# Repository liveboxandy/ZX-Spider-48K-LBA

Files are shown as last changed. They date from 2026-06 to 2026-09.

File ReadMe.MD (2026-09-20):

# ZX 48 Spider rework by liveboxandy
## ZX Spectrum 48 clone built on the basis of the ZX Max 48 design.

The board is designed to fit into the standard ZX Spectrum 48k or ZX Spectrum + housing.

## Characteristic:

* ULA based on the CPLD system from the Altera Max7000 family (EPM7128SLC84),
* 48KB RAM,
* AY-3-8910 or AY-3-8912 sound system with stereo output,
* Kempston standard joystick interface,
* RGB video output,
* possibility of using a power supply with any polarity,
* ROM bank switch,
* board fully adapted for through hole mounting

V1.0
* Uses MiniDIN 9 Pin for RGB same as ZX Max 128 & ZX MAx PLusD rather than MinDIN 8.
* Uses same Resistor values for RED/GREEN/BLUE/BRIGHT as ZX Max 128/PlusD/3/2A. 

V1.1
* Joystick can be disabled by removing J18.
* Option to supply +/-12V to edge connector for IF1 Serial support using PS1.

V1.2
* Routed AY3-8910 IOB Bits0-7 to header J18 Pins 1(Bit0)- 8(Bit7).
* Routed AY3-891X IOA Bits0-7 to header J20 Pins 1(Bit0)- 8(Bit7).
* Changed ROM select header to 2 pin rather than 3 pin so added pullup resistor.

V1.3
* Move MiniDIN 9 Pin right by ~2mm so it aligns better with the Video hole in the 14/48K and 48K+
* cases. 

V1.4 
* Correct value of R58 to 470R
* Add jumper J9 to select either 27C256 or 28C256
* Buffer 14Mhz clock more. Use all spare gates
* Label all jumpers

V1.5
* Move position and rotation Q2
* Slight repositioning of J6 (9Pin MiniDIN), R15/16/17/18/73 and J18

V1.6
* Move J6 MiniDIN 9 right by 0.5mm and down by 1mm to better align with 48K+ case.
* Move J11 Ear/Mic right by 0.5mm to better align with 48K+ case.
* Move components below J6 and J5 down to give more space.
* Move Edge Connector left by 0.8mm to centre within 48K+ case cutout.
* Add liveboxandy's Spider 48K V1.6 to silkscreen to try to track different revisions of PCB.

V1.7
* Add R20 for auto RGB selection. can be replaced with wire link if there is a 180R-270R resistor in the cable between miniDIN Pin 2 and Scart Pin 16 or can be left unpopulated if manual selection is used.
* Add R21 and D2 for auto AV 4:3 format. Requires PS1 (+12/-12V Converter) to be fitted. If manual selection, R21 and D2 can be left unpopulated.
* If PS1 is fitted the serial comms on IF1 will still NOT work unless C1 in the IF1 is replaced with a wire link. (The IF1 expects  12VAC which it uses to create -12VDC. The DCDC converter PS1 provides -12VDC but it is blocked by C1 in the IF1.)

See https://github.com/konkotgit/ZX-48-Spider Rev 1.1 for original information on the ZX Spider, especially if you have issues.
1) with BRIGHT being low or not visible - Might not, see above.
2) Tape loading issues.

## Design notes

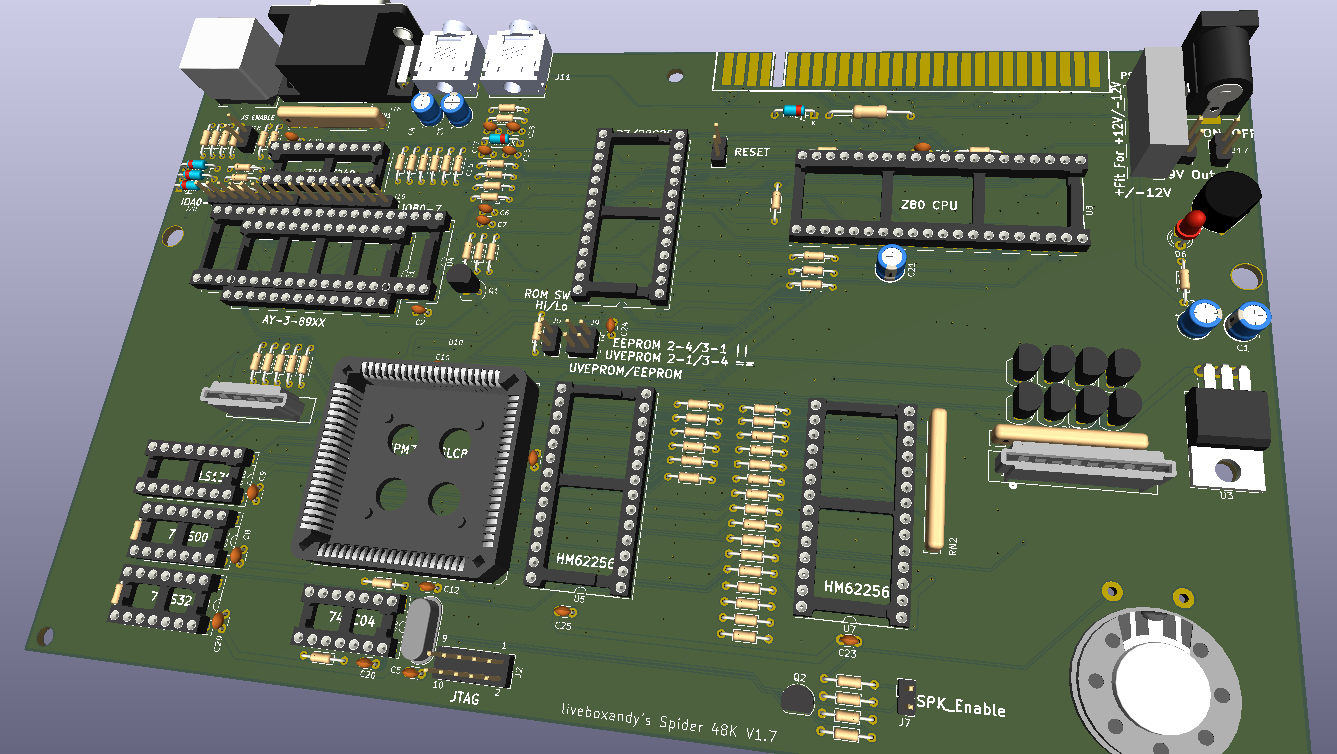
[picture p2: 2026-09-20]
ZXSpider48.png

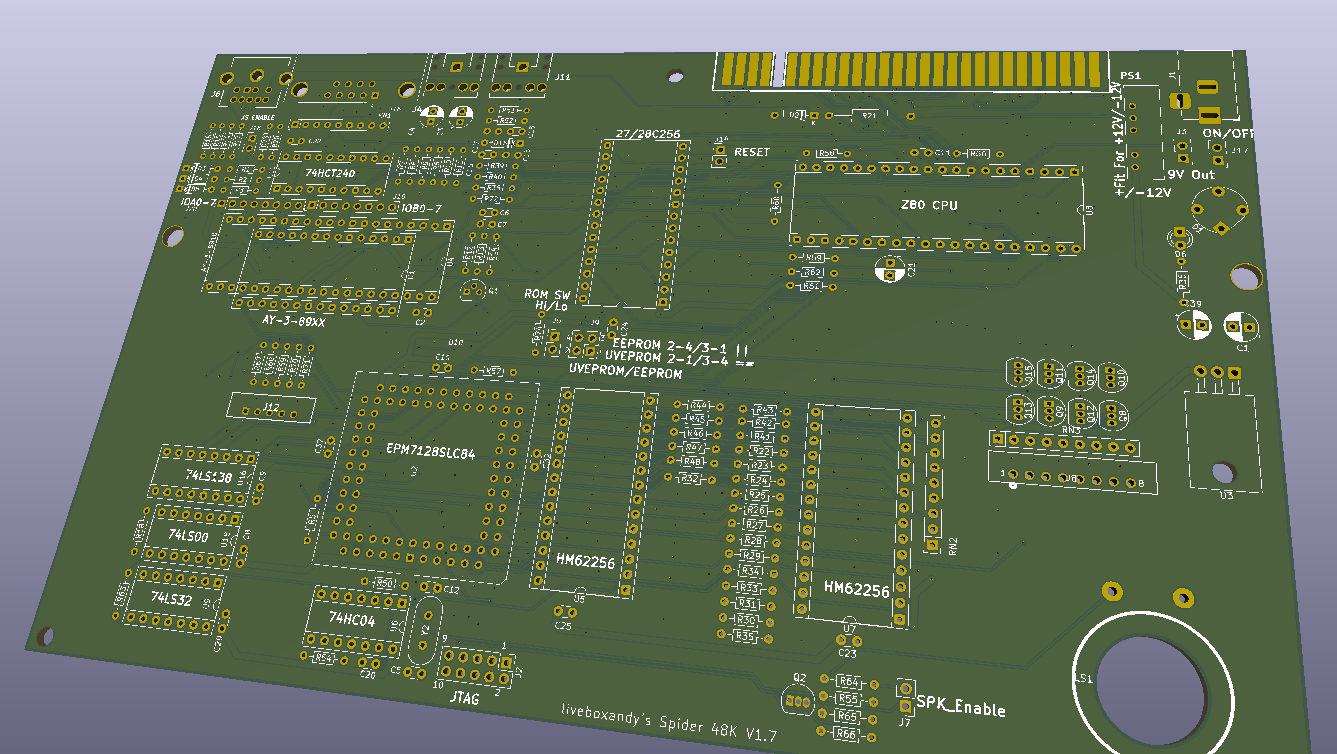
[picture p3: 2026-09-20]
ZXSpider48-Unpopulated.png

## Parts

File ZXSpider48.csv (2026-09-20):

Reference | Qty | Value | DNP | Exclude from BOM | Exclude from Board | Footprint | Datasheet
C1,C39 | 2 | 47uF |  |  |  | Capacitor_THT:CP_Radial_D5.0mm_P2.50mm
C2,C5,C6,C7,C8,C9,C10,C11,C12,C22,C23,C24,C25,C29,C32,C37 | 16 | 100n |  |  |  | Capacitor_THT:C_Disc_D3.0mm_W1.6mm_P2.50mm
C3,C4,C21 | 3 | 10uF |  |  |  | Capacitor_THT:CP_Radial_D5.0mm_P2.50mm
C15 | 1 | 10nF |  |  |  | Capacitor_THT:C_Disc_D3.0mm_W1.6mm_P2.50mm
C16 | 1 | 3.3nF |  |  |  | Capacitor_THT:C_Disc_D3.0mm_W1.6mm_P2.50mm
C17,C18 | 2 | 100nF |  |  |  | Capacitor_THT:C_Disc_D3.0mm_W1.6mm_P2.50mm
C20 | 1 | 100pF |  |  |  | Capacitor_THT:C_Disc_D3.0mm_W1.6mm_P2.50mm
D1 | 1 | Diode_Bridge |  |  |  | Diode_THT:Diode_Bridge_Round_D8.9mm
D2 | 1 | 12V |  |  |  | Diode_THT:D_DO-35_SOD27_P7.62mm_Horizontal
D3,D4,D5,D15 | 4 | 1N4148 |  |  |  | Diode_THT:D_DO-35_SOD27_P7.62mm_Horizontal
D6 | 1 | PWR LED |  |  |  | LED_THT:LED_D3.0mm
J1 | 1 | Barrel_Jack_Switch |  |  |  | Connector_BarrelJack:BarrelJack_Horizontal
J2 | 1 | JTAG |  |  |  | Connector_PinHeader_2.54mm:PinHeader_2x05_P2.54mm_Vertical
J3 | 1 | 9V |  |  |  | Connector_PinHeader_2.54mm:PinHeader_1x02_P2.54mm_Vertical
J4 | 1 | AUDIO |  |  |  | _MOD:SJ13525NGPI
J5 | 1 | ROM_SW |  |  |  | Connector_PinHeader_2.54mm:PinHeader_1x02_P2.54mm_Vertical
J6 | 1 | M-DIN KMDGX-9S-BS-1 |  |  |  | _MOD:KMDGX9SBS1 | http://service.powerdynamics.com/ec/Catalog17/Section%2011.pdf
J7 | 1 | SPK_ON_OFF |  |  |  | Connector_PinHeader_2.54mm:PinHeader_1x02_P2.54mm_Vertical
J8 | 1 | KB_CON_08 |  |  |  | _MOD:CONN_5-520315-8_TYC | 5-520315-8
J9 | 1 | UV/EEPROM |  |  |  | Connector_PinHeader_2.54mm:PinHeader_2x02_P2.54mm_Vertical
J11 | 1 | EAR/MIC |  |  |  | _MOD:SJ13525NGPI
J12 | 1 | KB_CONN_05 |  |  |  | _MOD:CONN_5-520315-5_TYC | https://www.te.com/commerce/DocumentDelivery/DDEController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
J14 | 1 | RESET |  |  |  | Connector_PinHeader_2.54mm:PinHeader_1x02_P2.54mm_Vertical
J15 | 1 | ZX_48K_EDGE |  |  |  | _MOD:ZX_BUS_A_TOP
J16 | 1 | DB9_Pins |  |  |  | Connector_Dsub:DSUB-9_Pins_Horizontal_P2.77x2.84mm_EdgePinOffset9.90mm_Housed_MountingHolesOffset11.32mm
J17 | 1 | ON/OFF |  |  |  | Connector_PinHeader_2.54mm:PinHeader_1x02_P2.54mm_Vertical
J18 | 1 | JS_ENABLE |  |  |  | Connector_PinHeader_2.54mm:PinHeader_1x02_P2.54mm_Vertical
J19 | 1 | AY3_IOB |  |  |  | Connector_PinHeader_2.54mm:PinHeader_1x08_P2.54mm_Vertical
J20 | 1 | AY3_IOA |  |  |  | Connector_PinHeader_2.54mm:PinHeader_1x08_P2.54mm_Vertical
LS1 | 1 | Speaker |  |  |  | _MOD:Speaker
PS1 | 1 | TBA_1-0522E |  |  |  | _MOD:TBA10522E | https://tracopower.com/tba1e-datasheet/
Q1 | 1 | BC517 |  |  |  | Package_TO_SOT_THT:TO-92 | https://www.onsemi.com/pub/Collateral/BC517-D74Z-D.PDF
Q2 | 1 | BC548 |  |  |  | Package_TO_SOT_THT:TO-92_Inline | https://www.onsemi.com/pub/Collateral/BC550-D.pdf
Q8,Q9,Q10,Q11,Q12,Q13,Q14,Q15 | 8 | BC560 |  |  |  | Package_TO_SOT_THT:TO-92_Inline | https://www.onsemi.com/pub/Collateral/BC556BTA-D.pdf
R1,R2,R3,R19 | 4 | 68R |  |  |  | Resistor_THT:R_Axial_DIN0204_L3.6mm_D1.6mm_P7.62mm_Horizontal
R5,R22,R23,R24,R25,R26,R27,R28,R29,R30,R31,R32,R33,R34,R35,R41,R42,R43,R44,R45,R46,R47,R48,R50,R51,R54,R57,R58 | 28 | 470R |  |  |  | Resistor_THT:R_Axial_DIN0204_L3.6mm_D1.6mm_P7.62mm_Horizontal
R6,R7 | 2 | 2K2 |  |  |  | Resistor_THT:R_Axial_DIN0204_L3.6mm_D1.6mm_P7.62mm_Horizontal
R8,R9,R10,R11 | 4 | 1K0 |  |  |  | Resistor_THT:R_Axial_DIN0204_L3.6mm_D1.6mm_P7.62mm_Horizontal
R12 | 1 | 4K7 |  |  |  | Resistor_THT:R_Axial_DIN0204_L3.6mm_D1.6mm_P7.62mm_Horizontal
R13,R14 | 2 | 150K |  |  |  | Resistor_THT:R_Axial_DIN0204_L3.6mm_D1.6mm_P7.62mm_Horizontal
R15,R16,R17,R36 | 4 | 150R |  |  |  | Resistor_THT:R_Axial_DIN0204_L3.6mm_D1.6mm_P7.62mm_Horizontal
R18,R38,R39,R40,R52,R55,R59,R60,R61,R62,R63,R67,R68,R69,R70,R71,R73,R74 | 18 | 10K |  |  |  | Resistor_THT:R_Axial_DIN0204_L3.6mm_D1.6mm_P7.62mm_Horizontal
R20 | 1 | 270R |  |  |  | Resistor_THT:R_Axial_DIN0204_L3.6mm_D1.6mm_P7.62mm_Horizontal
R21 | 1 | 150R |  |  |  | Resistor_THT:R_Axial_DIN0207_L6.3mm_D2.5mm_P15.24mm_Horizontal
R56 | 1 | 4.7K |  |  |  | Resistor_THT:R_Axial_DIN0204_L3.6mm_D1.6mm_P7.62mm_Horizontal
R64 | 1 | 0R |  |  |  | Resistor_THT:R_Axial_DIN0204_L3.6mm_D1.6mm_P7.62mm_Horizontal
R65,R66 | 2 | 33K |  |  |  | Resistor_THT:R_Axial_DIN0204_L3.6mm_D1.6mm_P7.62mm_Horizontal
R72 | 1 | 470K |  |  |  | Resistor_THT:R_Axial_DIN0204_L3.6mm_D1.6mm_P7.62mm_Horizontal
RN1,RN2,RN3 | 3 | 10K |  |  |  | Resistor_THT:R_Array_SIP9 | http://www.vishay.com/docs/31509/csc.pdf
U1 | 1 | AY-3-8912 |  |  |  | Package_DIP:DIP-28_W15.24mm_Socket | http://datasheets.diptrace.com\st_micro\M27C256B.pdf
U2 | 1 | EPM7128SLC84-10 |  |  |  | Package_LCC:PLCC-84_THT-Socket
U3 | 1 | LM7805_TO220 |  |  |  | Package_TO_SOT_THT:TO-220-3_Horizontal_TabDown | http://www.ti.com/lit/gpn/lm7800
U4 | 1 | AY-3-8910 |  |  |  | Package_DIP:DIP-40_W15.24mm_Socket
U5,U7 | 2 | HM62256 |  |  |  | Package_DIP:DIP-28_W15.24mm_Socket
U6 | 1 | 74HC04 |  |  |  | Package_DIP:DIP-14_W7.62mm_Socket | https://assets.nexperia.com/documents/data-sheet/74HC_HCT04.pdf
U8 | 1 | Z80 |  |  |  | Package_DIP:DIP-40_W15.24mm_Socket
U9 | 1 | 74LS32 |  |  |  | Package_DIP:DIP-14_W7.62mm_Socket | http://www.ti.com/lit/gpn/sn74LS32
U10 | 1 | 27/28C256 |  |  |  | Package_DIP:DIP-28_W15.24mm_Socket
U11 | 1 | 74HCT240 |  |  |  | Package_DIP:DIP-20_W7.62mm_Socket | https://assets.nexperia.com/documents/data-sheet/74HC_HCT240.pdf
U16 | 1 | 74LS138 |  |  |  | Package_DIP:DIP-16_W7.62mm_Socket | http://www.ti.com/lit/gpn/sn74LS138
U18 | 1 | 74LS00 |  |  |  | Package_DIP:DIP-14_W7.62mm_Socket | http://www.ti.com/lit/gpn/sn74ls00
Y2 | 1 | 14.000 Mhz |  |  |  | Crystal:Crystal_HC49-4H_Vertical

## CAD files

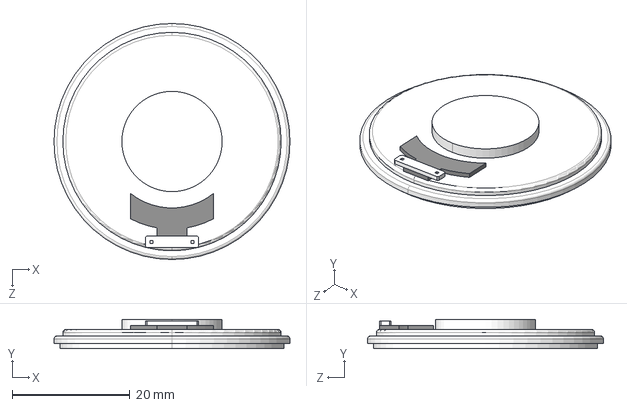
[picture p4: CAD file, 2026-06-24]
STP/GC0402MA.stp
40.0 x 4.93 x 40.0 mm

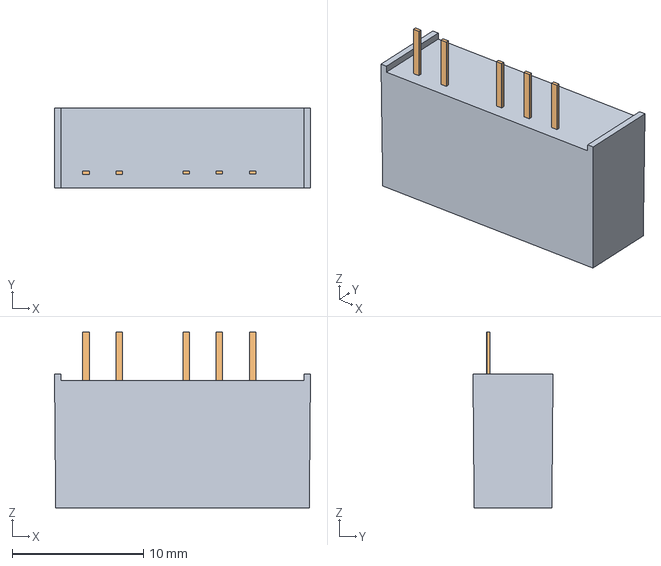
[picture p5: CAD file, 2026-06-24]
STP/TBA-1-0522E.stp
19.5 x 6.10 x 13.4 mm

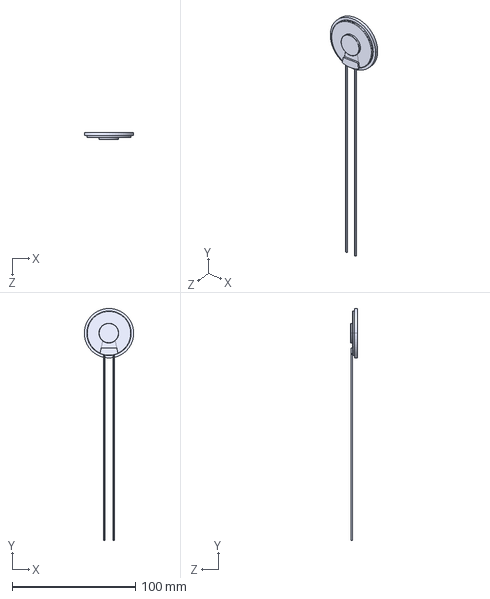
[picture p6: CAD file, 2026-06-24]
STP/CMS-40558N-L152B.stp
40.0 x 187.9 x 5.50 mm

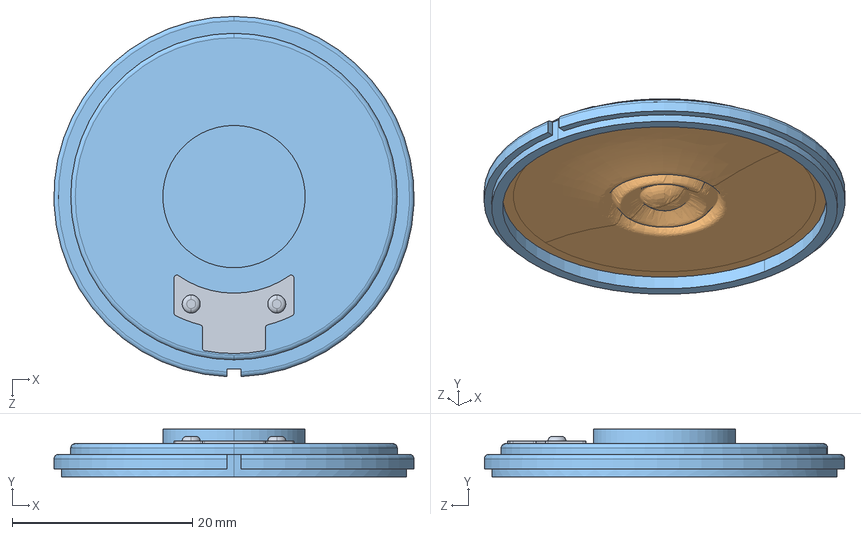
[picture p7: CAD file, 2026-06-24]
STP/CLS0402MA-1.stp
40.0 x 5.30 x 40.0 mm

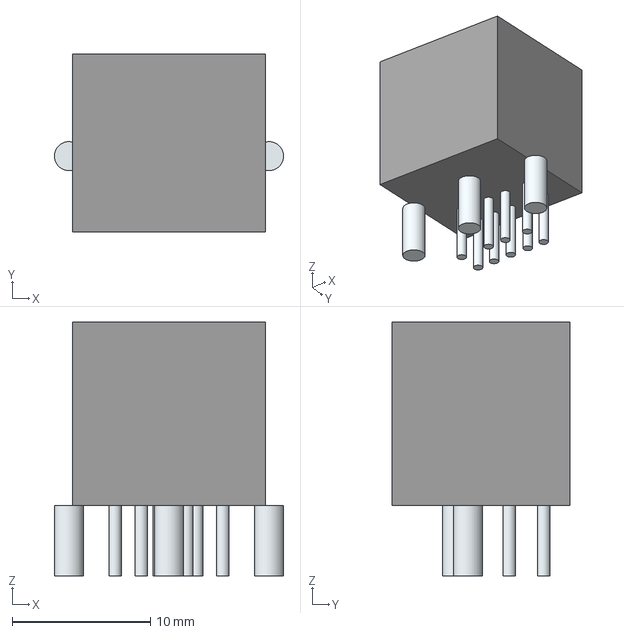
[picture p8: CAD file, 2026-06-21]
STP/9Pin MiniDIN KMDGX-9S-BS-1.stp
16.6 x 12.9 x 18.4 mm
Leads

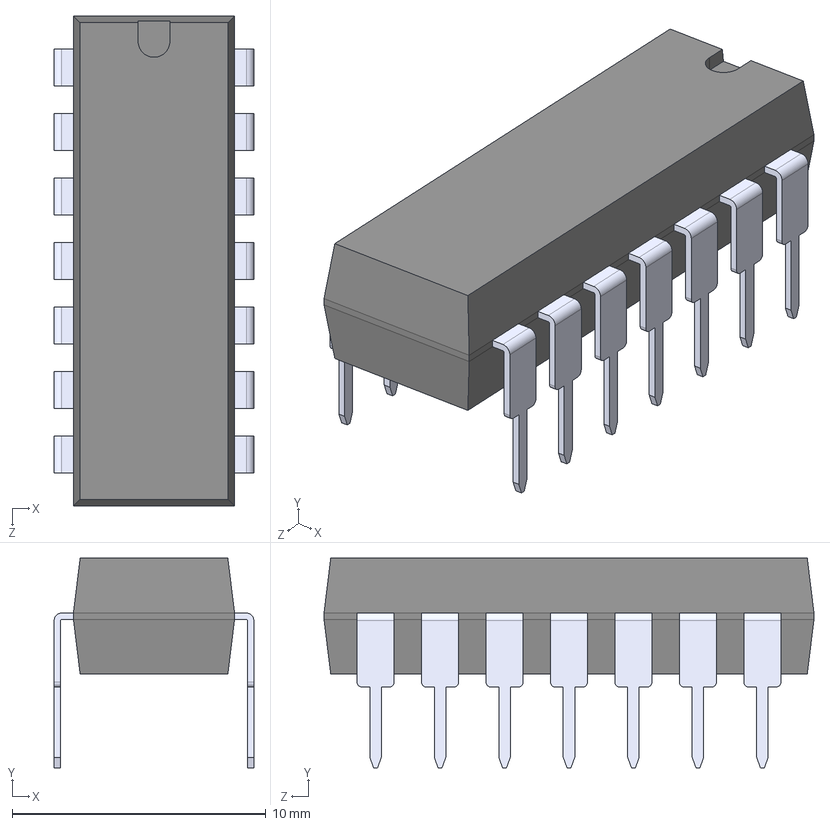
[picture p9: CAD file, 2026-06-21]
STP/SN74HC32N.step
7.87 x 8.26 x 19.3 mm

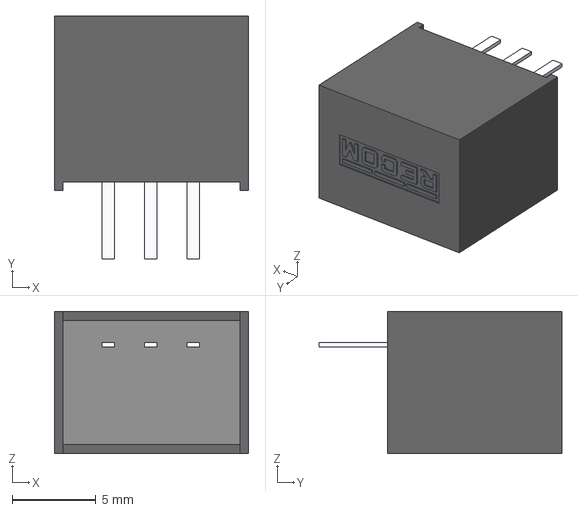
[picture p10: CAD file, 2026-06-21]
STP/R-78E5.0-1.0.step
11.6 x 14.5 x 8.50 mm

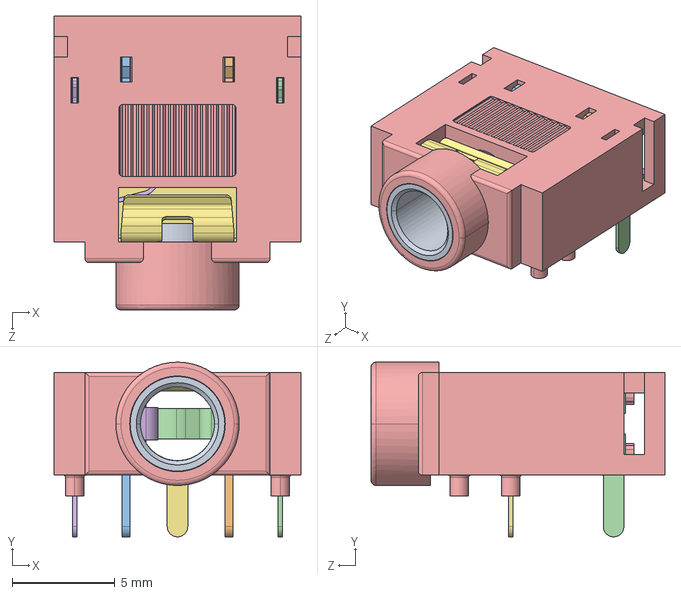
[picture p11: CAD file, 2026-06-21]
STP/SJ1-3525NG-PI.stp
12.0 x 8.50 x 14.3 mm

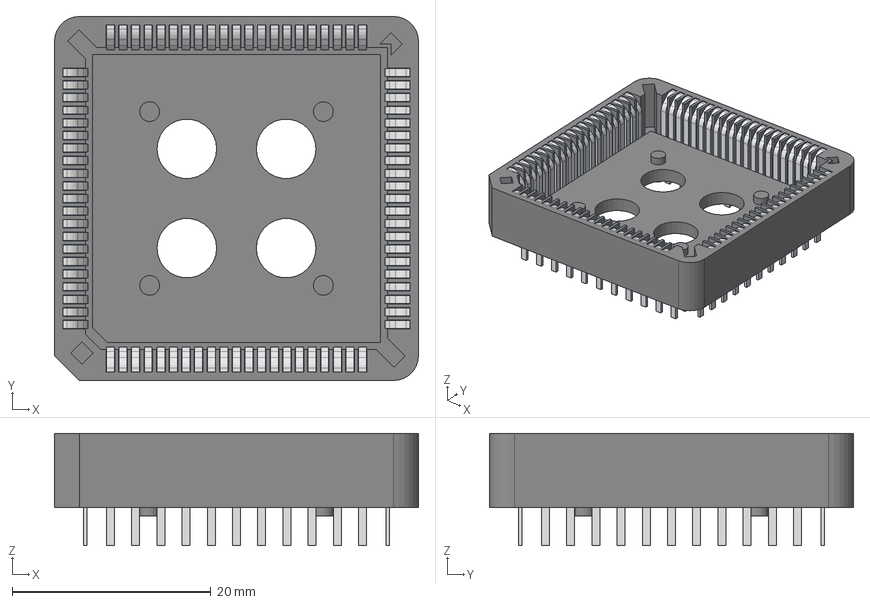
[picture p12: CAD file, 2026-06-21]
STP/PLCC-84-AT.stp
36.7 x 36.7 x 11.3 mm

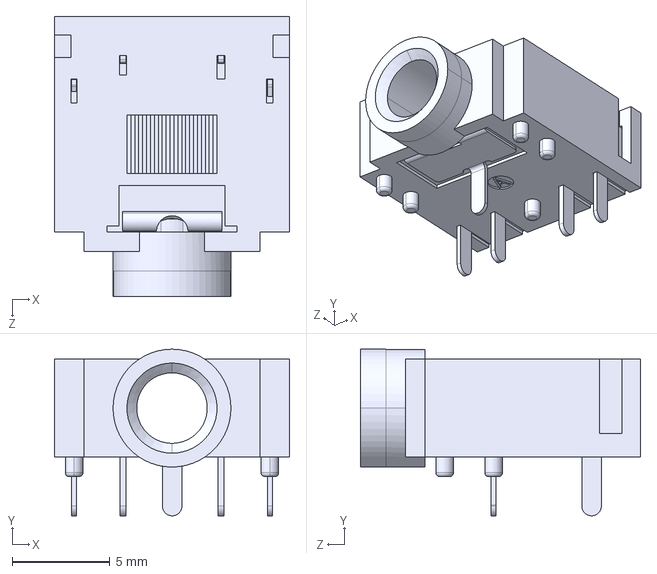
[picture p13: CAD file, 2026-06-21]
STP/SJ1-3525N.step
12.0 x 8.51 x 14.3 mm

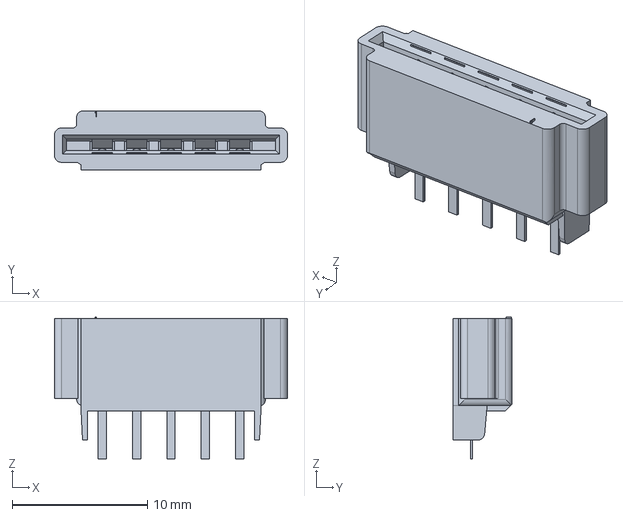
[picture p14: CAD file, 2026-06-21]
STP/5-520315-5.stp
17.2 x 4.39 x 10.5 mm

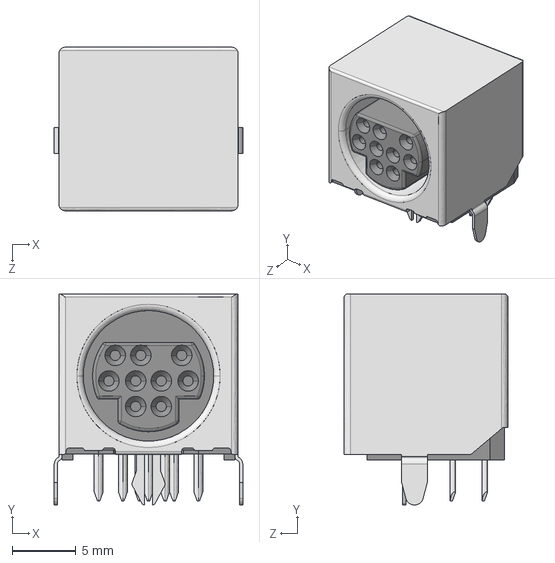
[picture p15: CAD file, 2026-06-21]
STP/KMDGX-9S-BS-1_A1.IGS
14.8 x 16.5 x 12.8 mm

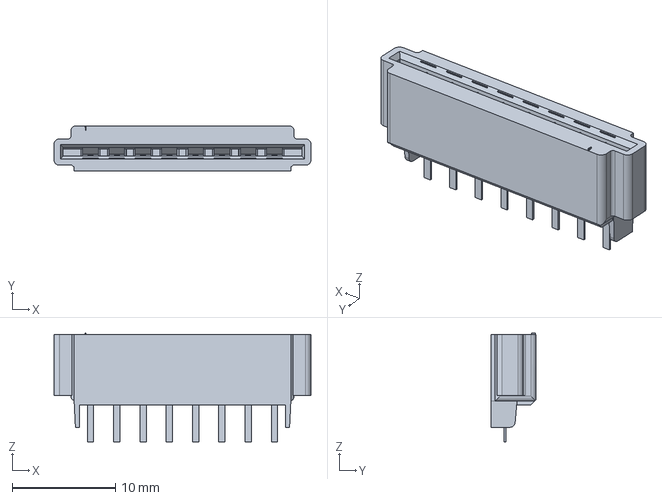
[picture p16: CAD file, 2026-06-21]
STP/CONN_5-520315-8_TYC.stp
24.8 x 4.39 x 10.5 mm

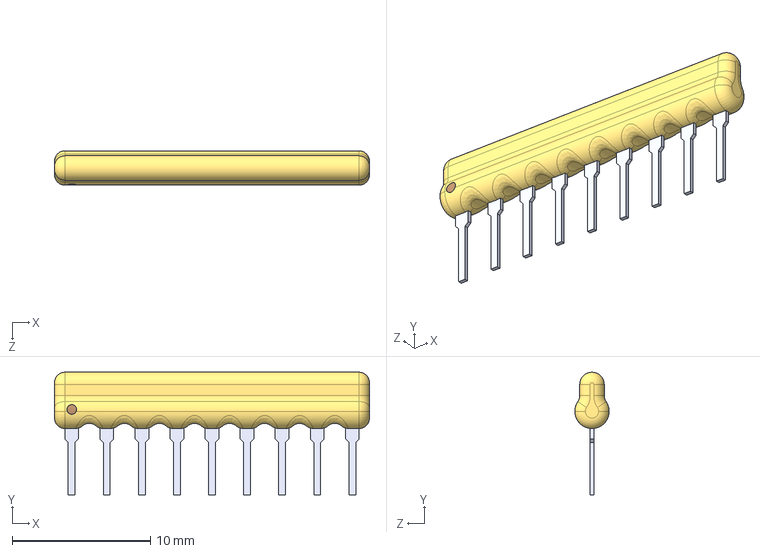
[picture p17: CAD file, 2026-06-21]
STP/RNET 10K 9PIn 4609X-101-103LF.step
22.8 x 8.88 x 2.49 mm

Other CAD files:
STP/SM230332-2.stp
STP/1658998-1.stp

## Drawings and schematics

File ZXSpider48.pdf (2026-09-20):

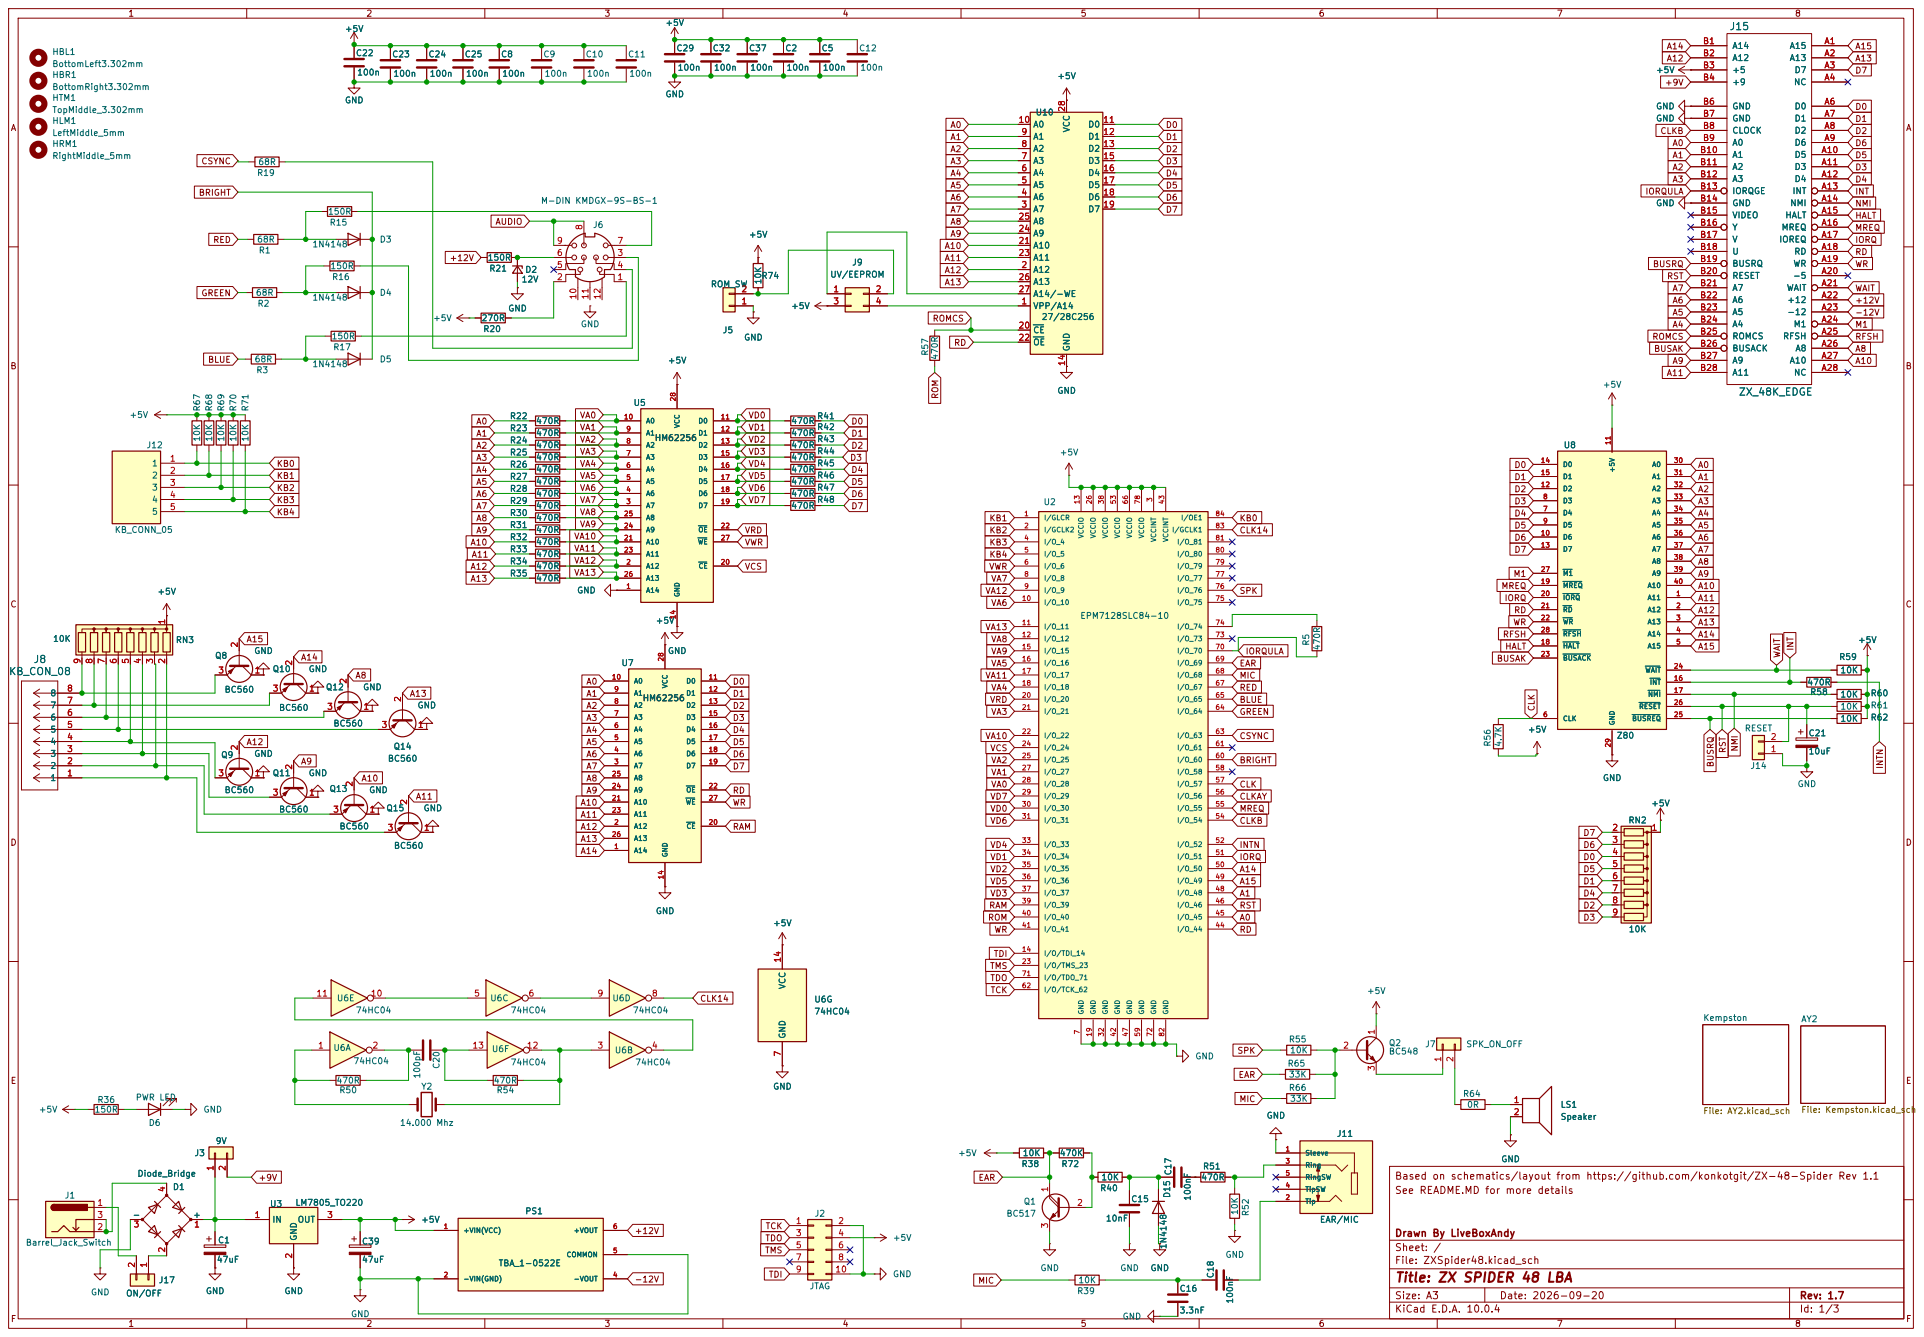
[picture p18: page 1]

7 GND 19 VCCIO 26 GND 32 VCCIO 38 GND 42 VCCINT 43 GND 47 VCCIO 53 GND 59 VCCIO 66 GND 72 VCCIO 78 GND 82

Based on schematics/layout from https://github.com/konkotgit/ZX-48-Spider Rev 1.1
See README.MD for more details

Drawn By LiveBoxAndy
Sheet: /
File: ZXSpider48.kicad_sch
Title: ZX SPIDER 48 LBA

Size: A3 | Rev: 1.7
KiCad E.D.A. 10.0.4 | Id: 1/3 | F Date: 2026-09-20

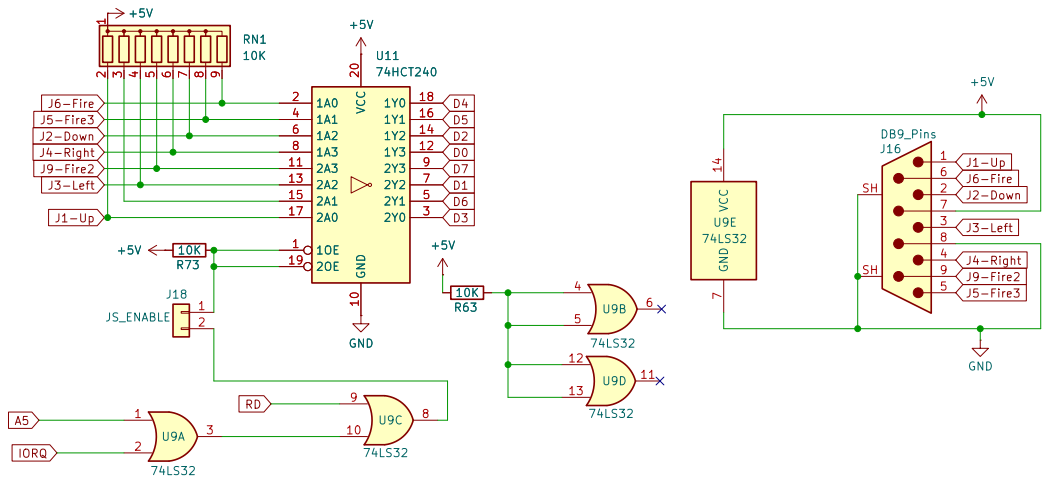
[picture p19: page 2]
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

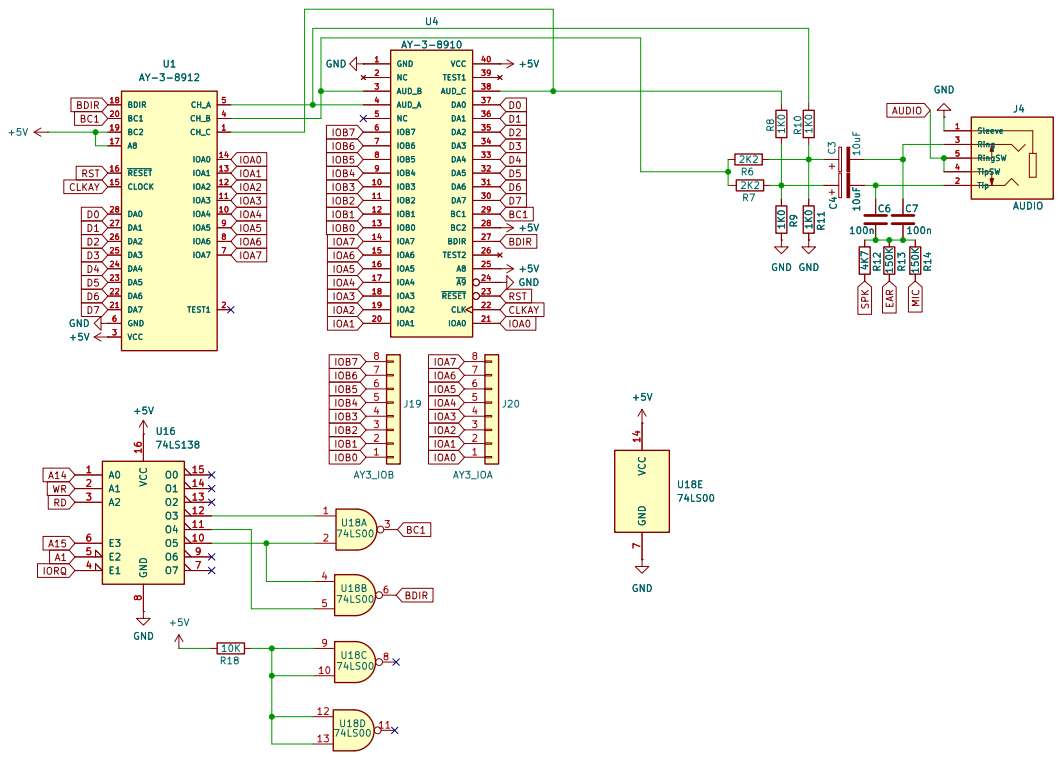
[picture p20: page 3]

See README.MD for more details

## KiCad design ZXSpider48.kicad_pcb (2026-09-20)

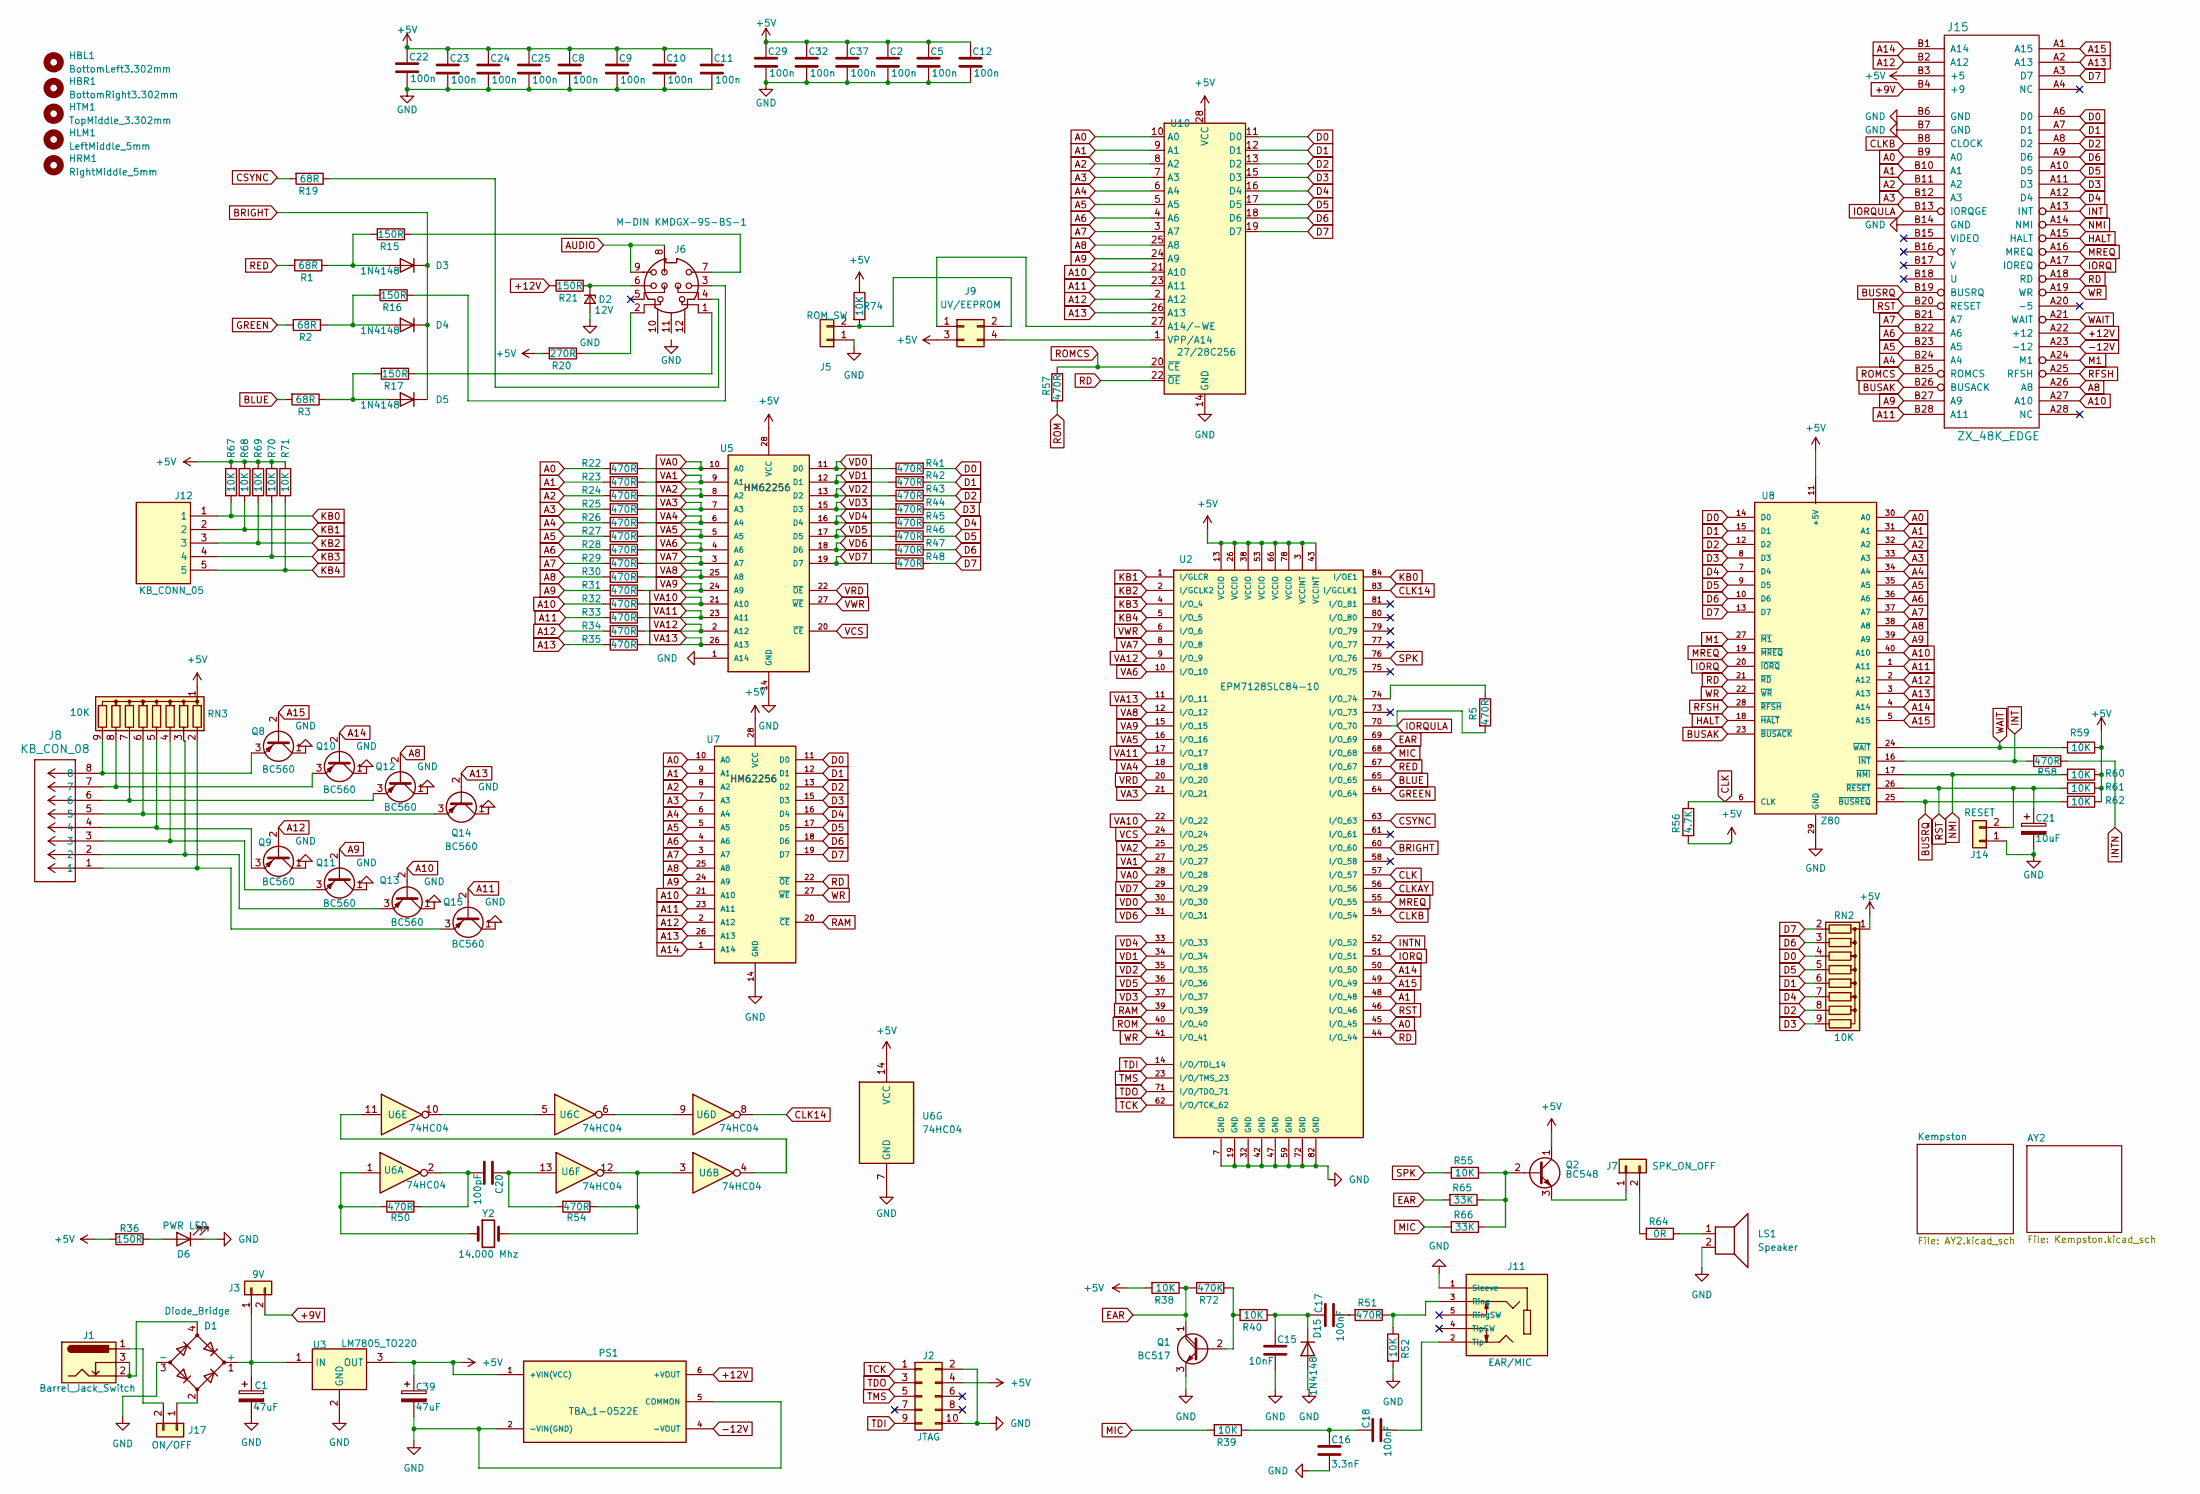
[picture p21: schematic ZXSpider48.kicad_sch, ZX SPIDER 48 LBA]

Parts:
C1, C39: 47uF; CP_Radial_D5.0mm_P2.50mm
C2, C5, C8, C9, C10, C11, C12, C22, C23, C24, C25, C29, C32, C37: 100n; C_Disc_D3.0mm_W1.6mm_P2.50mm
C15: 10nF; C_Disc_D3.0mm_W1.6mm_P2.50mm
C16: 3.3nF; C_Disc_D3.0mm_W1.6mm_P2.50mm
C17, C18: 100nF; C_Disc_D3.0mm_W1.6mm_P2.50mm
C20: 100pF; C_Disc_D3.0mm_W1.6mm_P2.50mm
C21: 10uF; CP_Radial_D5.0mm_P2.50mm
D1: Diode_Bridge; Diode_Bridge_Round_D8.9mm
D2: 12V; D_DO-35_SOD27_P7.62mm_Horizontal
D3, D4, D5, D15: 1N4148; D_DO-35_SOD27_P7.62mm_Horizontal
D6: PWR LED; LED_D3.0mm
HBL1: BottomLeft3.302mm; MountingHole_3.3mm Spectrum
HBR1: BottomRight3.302mm; MountingHole_3.3mm Spectrum
HLM1: LeftMiddle_5mm; MountingHole_5mm Spectrum
HRM1: RightMiddle_5mm; MountingHole_5mm Spectrum
HTM1: TopMiddle_3.302mm; MountingHole_3.3mm Spectrum
J1: Barrel_Jack_Switch; BarrelJack_Horizontal
J2: JTAG; PinHeader_2x05_P2.54mm_Vertical
J3: 9V; PinHeader_1x02_P2.54mm_Vertical
J5: ROM_SW; PinHeader_1x02_P2.54mm_Vertical
J6: M-DIN KMDGX-9S-BS-1; KMDGX9SBS1
J7: SPK_ON_OFF; PinHeader_1x02_P2.54mm_Vertical
J8: KB_CON_08; CONN_5-520315-8_TYC
J9: UV/EEPROM; PinHeader_2x02_P2.54mm_Vertical
J11: EAR/MIC; SJ13525NGPI; PARTREV 1.05
J12: KB_CONN_05; CONN_5-520315-5_TYC; Mouser Part Number 571-5-520315-5
J14: RESET; PinHeader_1x02_P2.54mm_Vertical
J15: ZX_48K_EDGE; ZX_BUS_A_TOP
J17: ON/OFF; PinHeader_1x02_P2.54mm_Vertical
LS1: Speaker
PS1: TBA_1-0522E; TBA10522E; Mouser Part Number 495-TBA1-0522E
Q1: BC517; TO-92
Q2: BC548; TO-92_Inline
Q8, Q9, Q10, Q11, Q12, Q13, Q14, Q15: BC560; TO-92_Inline
R1, R2, R3, R19: 68R; R_Axial_DIN0204_L3.6mm_D1.6mm_P7.62mm_Horizontal
R5, R22, R23, R24, R25, R26, R27, R28, R29, R30, R31, R32, R33, R34, R35, R41, R42, R43, R44, R45, R46, R47, R48, R50, R51, R54, R57, R58: 470R; R_Axial_DIN0204_L3.6mm_D1.6mm_P7.62mm_Horizontal
R15, R16, R17, R36: 150R; R_Axial_DIN0204_L3.6mm_D1.6mm_P7.62mm_Horizontal
R20: 270R; R_Axial_DIN0204_L3.6mm_D1.6mm_P7.62mm_Horizontal
R21: 150R; R_Axial_DIN0207_L6.3mm_D2.5mm_P15.24mm_Horizontal
R38, R39, R40, R52, R55, R59, R60, R61, R62, R67, R68, R69, R70, R71, R74: 10K; R_Axial_DIN0204_L3.6mm_D1.6mm_P7.62mm_Horizontal
R56: 4.7K; R_Axial_DIN0204_L3.6mm_D1.6mm_P7.62mm_Horizontal
R64: 0R; R_Axial_DIN0204_L3.6mm_D1.6mm_P7.62mm_Horizontal
R65, R66: 33K; R_Axial_DIN0204_L3.6mm_D1.6mm_P7.62mm_Horizontal
R72: 470K; R_Axial_DIN0204_L3.6mm_D1.6mm_P7.62mm_Horizontal
RN2, RN3: 10K; R_Array_SIP9
U2: EPM7128SLC84-10; PLCC-84_THT-Socket; PARTREV 6.7
U3: LM7805_TO220; TO-220-3_Horizontal_TabDown; Mouser Part Number 926-LM7805CT/NOPB
U5, U7: HM62256; DIP-28_W15.24mm_Socket
U6: 74HC04; DIP-14_W7.62mm_Socket
U8: Z80; DIP-40_W15.24mm_Socket
U10: 27/28C256; DIP-28_W15.24mm_Socket
Y2: 14.000 Mhz; Crystal_HC49-4H_Vertical

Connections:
+5V: C2.1, C5.1, C8.1, C9.1, C10.1, C11.1, C12.1, C22.1, C23.1, C24.1, C25.1, C29.1, C32.1, C37.1, C39.1, J2.4, J9.3, J15.B3 (+5), PS1.1 (+VIN(VCC)), Q2.1 (C), R20.2, R36.2, R38.2, R56.2, R59.1, R60.1, R61.1, R62.1, R67.1, R68.1, R69.1, R70.1, R71.1, R74.1, RN2.1 (common), RN3.1 (common), U2.3 (VCCINT), U2.13 (VCCIO), U2.26 (VCCIO), U2.38 (VCCIO), U2.43 (VCCINT), U2.53 (VCCIO), U2.66 (VCCIO), U2.78 (VCCIO), U3.3 (OUT), U5.28 (VCC), U6.14 (VCC), U7.28 (VCC), U8.11 (+5V), U10.28 (VCC); also elsewhere on the board
+9V: J3.2, J15.B4 (+9)
+12V: J15.A22 (+12), PS1.6 (+VOUT), R21.2
-12V: J15.A23 (-12), PS1.4 (-VOUT)
A0: J15.B9 (A0), R22.2, U2.45 (I/O_45), U7.10 (A0), U8.30 (A0), U10.10 (A0)
A1: J15.B10 (A1), R23.2, U2.48 (I/O_48), U7.9 (A1), U8.31 (A1), U10.9 (A1); also elsewhere on the board
A2: J15.B11 (A2), R24.2, U7.8 (A2), U8.32 (A2), U10.8 (A2)
A3: J15.B12 (A3), R25.2, U7.7 (A3), U8.33 (A3), U10.7 (A3)
A4: J15.B24 (A4), R26.2, U7.6 (A4), U8.34 (A4), U10.6 (A4)
A5: J15.B23 (A5), R27.2, U7.5 (A5), U8.35 (A5), U10.5 (A5); also elsewhere on the board
A6: J15.B22 (A6), R28.2, U7.4 (A6), U8.36 (A6), U10.4 (A6)
A7: J15.B21 (A7), R29.2, U7.3 (A7), U8.37 (A7), U10.3 (A7)
A8: J15.A26 (A8), Q12.2 (B), R30.2, U7.25 (A8), U8.38 (A8), U10.25 (A8)
A9: J15.B27 (A9), Q11.2 (B), R31.2, U7.24 (A9), U8.39 (A9), U10.24 (A9)
A10: J15.A27 (A10), Q13.2 (B), R32.2, U7.21 (A10), U8.40 (A10), U10.21 (A10)
A11: J15.B28 (A11), Q15.2 (B), R33.2, U7.23 (A11), U8.1 (A11), U10.23 (A11)
A12: J15.B2 (A12), Q9.2 (B), R34.2, U7.2 (A12), U8.2 (A12), U10.2 (A12)
A13: J15.A2 (A13), Q14.2 (B), R35.2, U7.26 (A13), U8.3 (A13), U10.26 (A13)
A14: J15.B1 (A14), Q10.2 (B), U2.50 (I/O_50), U7.1 (A14), U8.4 (A14); also elsewhere on the board
A15: J15.A1 (A15), Q8.2 (B), U2.49 (I/O_49), U8.5 (A15); also elsewhere on the board
AUDIO: J6.8, J6.9; also elsewhere on the board
BLUE: R3.2, U2.65 (I/O_65)
BRIGHT: D3.1 (K), D4.1 (K), D5.1 (K), U2.60 (I/O_60)
BUSAK: J15.B26 (BUSACK), U8.23 (~BUSACK)
BUSRQ: J15.B19 (BUSRQ), R62.2, U8.25 (~BUSREQ)
CLK: R56.1, U2.57 (I/O_57), U8.6 (CLK)
CLK14: U2.83 (I/GCLK1), U6.8
CLKAY: U2.56 (I/O_56); also elsewhere on the board
CLKB: J15.B8 (CLOCK), U2.54 (I/O_54)
CSYNC: R19.2, U2.63 (I/O_63)
D0: J15.A6 (D0), R41.2, RN2.4 (R3), U7.11 (D0), U8.14 (D0), U10.11 (D0); also elsewhere on the board
D1: J15.A7 (D1), R42.2, RN2.6 (R5), U7.12 (D1), U8.15 (D1), U10.12 (D1); also elsewhere on the board
D2: J15.A8 (D2), R43.2, RN2.8 (R7), U7.13 (D2), U8.12 (D2), U10.13 (D2); also elsewhere on the board
D3: J15.A11 (D3), R44.1, RN2.9 (R8), U7.15 (D3), U8.8 (D3), U10.15 (D3); also elsewhere on the board
D4: J15.A12 (D4), R45.1, RN2.7 (R6), U7.16 (D4), U8.7 (D4), U10.16 (D4); also elsewhere on the board
D5: J15.A10 (D5), R46.1, RN2.5 (R4), U7.17 (D5), U8.9 (D5), U10.17 (D5); also elsewhere on the board
D6: J15.A9 (D6), R47.1, RN2.3 (R2), U7.18 (D6), U8.10 (D6), U10.18 (D6); also elsewhere on the board
D7: J15.A3 (D7), R48.1, RN2.2 (R1), U7.19 (D7), U8.13 (D7), U10.19 (D7); also elsewhere on the board
EAR: Q1.1 (C), R38.1, R65.2, R72.2, U2.69 (I/O_69); also elsewhere on the board
GND: C1.2, C2.2, C5.2, C8.2, C9.2, C10.2, C11.2, C12.2, C15.2, C16.2, C21.2, C22.2, C23.2, C24.2, C25.2, C29.2, C32.2, C37.2, C39.2, D1.3 (-), D2.2 (A), D6.1 (K), D15.2 (A), J2.2, J2.10, J5.1, J11.1 (Sleeve), J14.1, J15.B6 (GND), J15.B7 (GND), J15.B14 (GND), LS1.2, PS1.2 (-VIN(GND)), PS1.5 (COMMON), Q1.3 (E), Q8.1 (C), Q9.1 (C), Q10.1 (C), Q11.1 (C), Q12.1 (C), Q13.1 (C), Q14.1 (C), Q15.1 (C), R52.2, U2.7 (GND), U2.19 (GND), U2.32 (GND), U2.42 (GND), U2.47 (GND), U2.59 (GND), U2.72 (GND), U2.82 (GND), U3.2 (GND), U5.1 (A14), U5.14 (GND), U6.7 (GND), U7.14 (GND), U8.29 (GND), U10.14 (GND); also elsewhere on the board
GREEN: R2.2, U2.64 (I/O_64)
HALT: J15.A15 (HALT), U8.18 (~HALT)
INT: J15.A13 (INT), R58.2, U8.16 (~INT)
INTN: R58.1, U2.52 (I/O_52)
IORQ: J15.A17 (IOREQ), U2.51 (I/O_51), U8.20 (~IORQ); also elsewhere on the board
IORQULA: J15.B13 (IORQGE), R5.2, U2.70 (I/O_70)
KB0: J12.1, R67.2, U2.84 (I/OE1)
KB1: J12.2, R68.2, U2.1 (I/GLCR)
KB2: J12.3, R69.2, U2.2 (I/GCLK2)
KB3: J12.4, R70.2, U2.4 (I/O_4)
KB4: J12.5, R71.2, U2.5 (I/O_5)
M1: J15.A24 (M1), U8.27 (~M1)
MIC: R39.2, R66.2, U2.68 (I/O_68); also elsewhere on the board
MREQ: J15.A16 (MREQ), U2.55 (I/O_55), U8.19 (~MREQ)
NMI: J15.A14 (NMI), R60.2, U8.17 (~NMI)
unnamed: C16.1, C18.1, R39.1
unnamed: C17.2, R51.2
unnamed: C20.1, R50.1, U6.2
unnamed: C20.2, R54.2, U6.13
unnamed: C1.1, D1.1 (+), J3.1, U3.1 (IN)
unnamed: D1.4, J1.2, J1.3
unnamed: D2.1 (K), J6.6, R21.1
unnamed: D3.2 (A), R1.1, R15.2
unnamed: D4.2 (A), R2.1, R16.2
unnamed: D5.2 (A), R3.1, R17.2
unnamed: D6.2 (A), R36.1
unnamed: C15.1, C17.1, D15.1 (K), R40.1
unnamed: J5.2, J9.2, R74.2
unnamed: J6.1, R17.1
unnamed: J6.2, R20.1
unnamed: J6.3, R16.1
unnamed: J6.4, R19.1
unnamed: J6.7, R15.1
unnamed: J7.1, Q2.3 (E)
unnamed: J7.2, R64.2
unnamed: J9.1, U10.27 (A14/-WE)
unnamed: J9.4, U10.1 (VPP/A14)
unnamed: J11.3 (Ring), R51.1, R52.1
unnamed: C18.2, J11.2 (Tip)
unnamed: D1.2, J17.1
unnamed: J1.1, J17.2
unnamed: LS1.1, R64.1
unnamed: Q1.2 (B), R40.2, R72.1
unnamed: Q2.2 (B), R55.1, R65.1, R66.1
unnamed: J8.8, Q8.3 (E), RN3.9 (R8)
unnamed: J8.4, Q9.3 (E), RN3.5 (R4)
unnamed: J8.7, Q10.3 (E), RN3.8 (R7)
unnamed: J8.3, Q11.3 (E), RN3.4 (R3)
unnamed: J8.6, Q12.3 (E), RN3.7 (R6)
unnamed: J8.2, Q13.3 (E), RN3.3 (R2)
unnamed: J8.5, Q14.3 (E), RN3.6 (R5)
unnamed: J8.1, Q15.3 (E), RN3.2 (R1)
unnamed: R50.2, U6.1, Y2.1
unnamed: R54.1, U6.3, U6.12, Y2.2
unnamed: R5.1, U2.74 (I/O_74)
unnamed: U6.6, U6.9
unnamed: U6.5, U6.10
unnamed: U6.4, U6.11
RAM: U2.39 (I/O_39), U7.20 (~CE)
RD: J15.A18 (RD), U2.44 (I/O_44), U7.22 (~OE), U8.21 (~RD), U10.22 (~OE); also elsewhere on the board
RED: R1.2, U2.67 (I/O_67)
RFSH: J15.A25 (RFSH), U8.28 (~RFSH)
ROM: R57.2, U2.40 (I/O_40)
ROMCS: J15.B25 (ROMCS), R57.1, U10.20 (~CE)
RST: C21.1, J14.2, J15.B20 (RESET), R61.2, U2.46 (I/O_46), U8.26 (~RESET); also elsewhere on the board
SPK: R55.2, U2.76 (I/O_76); also elsewhere on the board
TCK: J2.1, U2.62 (I/O/TCK_62)
TDI: J2.9, U2.14 (I/O/TDI_14)
TDO: J2.3, U2.71 (I/O/TDO_71)
TMS: J2.5, U2.23 (I/O/TMS_23)
VA0: R22.1, U2.28 (I/O_28), U5.10 (A0)
VA1: R23.1, U2.27 (I/O_27), U5.9 (A1)
VA2: R24.1, U2.25 (I/O_25), U5.8 (A2)
VA3: R25.1, U2.21 (I/O_21), U5.7 (A3)
VA4: R26.1, U2.18 (I/O_18), U5.6 (A4)
VA5: R27.1, U2.16 (I/O_16), U5.5 (A5)
VA6: R28.1, U2.10 (I/O_10), U5.4 (A6)
VA7: R29.1, U2.8 (I/O_8), U5.3 (A7)
VA8: R30.1, U2.12 (I/O_12), U5.25 (A8)
VA9: R31.1, U2.15 (I/O_15), U5.24 (A9)
VA10: R32.1, U2.22 (I/O_22), U5.21 (A10)
VA11: R33.1, U2.17 (I/O_17), U5.23 (A11)
VA12: R34.1, U2.9 (I/O_9), U5.2 (A12)
VA13: R35.1, U2.11 (I/O_11), U5.26 (A13)
VCS: U2.24 (I/O_24), U5.20 (~CE)
VD0: R41.1, U2.30 (I/O_30), U5.11 (D0)
VD1: R42.1, U2.34 (I/O_34), U5.12 (D1)
VD2: R43.1, U2.35 (I/O_35), U5.13 (D2)
VD3: R44.2, U2.37 (I/O_37), U5.15 (D3)
VD4: R45.2, U2.33 (I/O_33), U5.16 (D4)
VD5: R46.2, U2.36 (I/O_36), U5.17 (D5)
VD6: R47.2, U2.31 (I/O_31), U5.18 (D6)
VD7: R48.2, U2.29 (I/O_29), U5.19 (D7)
VRD: U2.20 (I/O_20), U5.22 (~OE)
VWR: U2.6 (I/O_6), U5.27 (~WE)
WAIT: J15.A21 (WAIT), R59.2, U8.24 (~WAIT)
WR: J15.A19 (WR), U2.41 (I/O_41), U7.27 (~WE), U8.22 (~WR); also elsewhere on the board

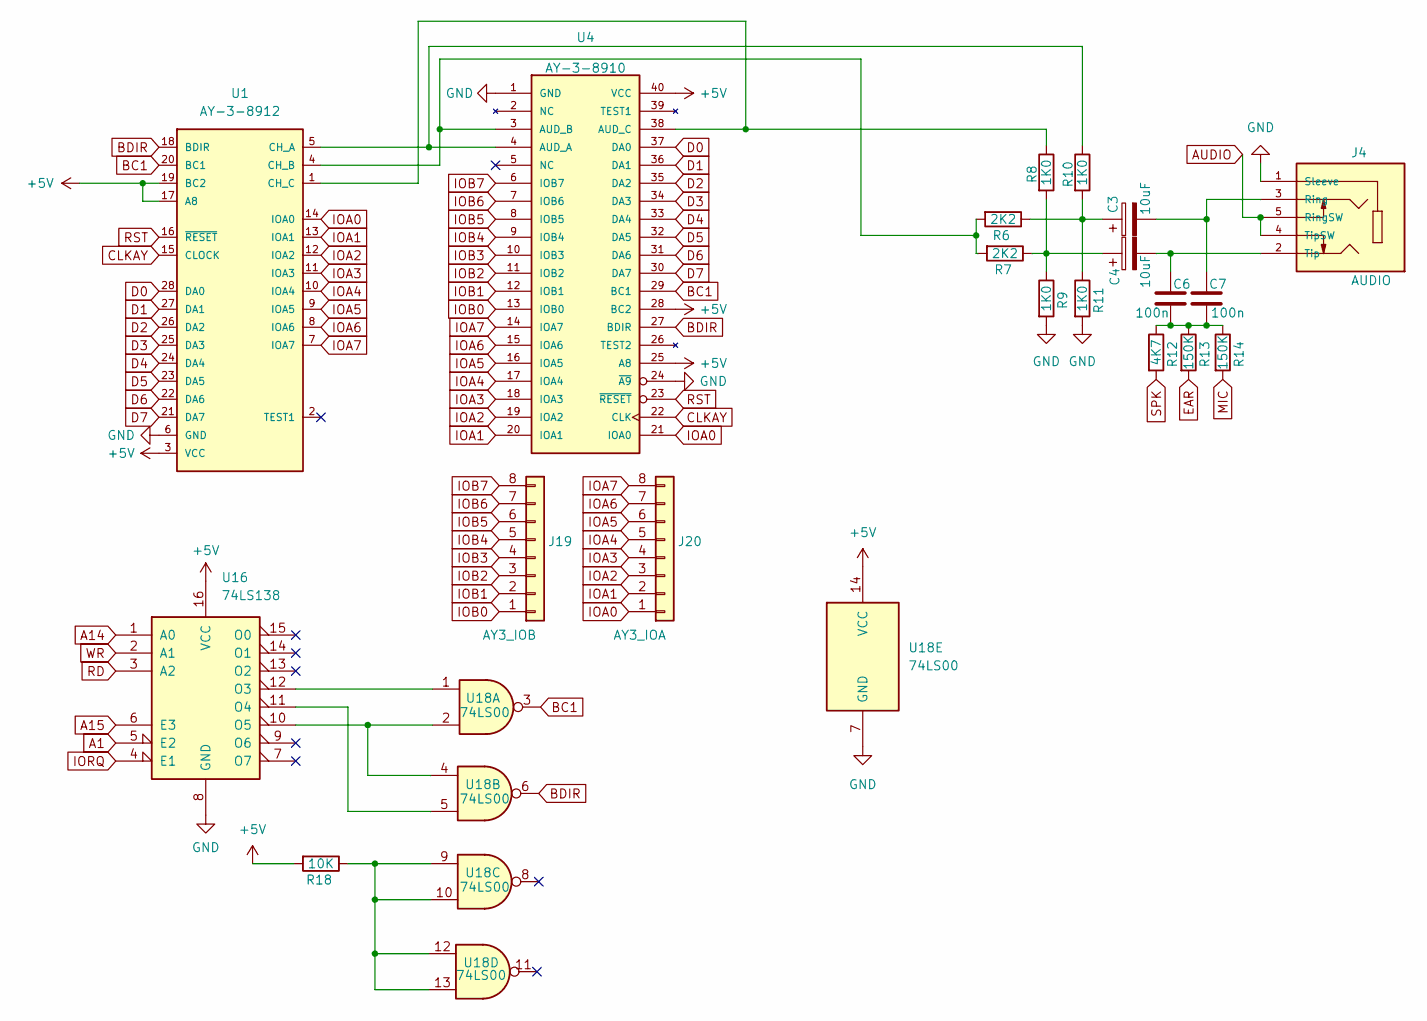
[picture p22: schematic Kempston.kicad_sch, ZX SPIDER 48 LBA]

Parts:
C3, C4: 10uF; CP_Radial_D5.0mm_P2.50mm
C6, C7: 100n; C_Disc_D3.0mm_W1.6mm_P2.50mm
J4: AUDIO; SJ13525NGPI; PARTREV 1.05; Mouser Part Number 490-SJ1-3525NG-PI
J19: AY3_IOB; PinHeader_1x08_P2.54mm_Vertical
J20: AY3_IOA; PinHeader_1x08_P2.54mm_Vertical
R6, R7: 2K2; R_Axial_DIN0204_L3.6mm_D1.6mm_P7.62mm_Horizontal
R8, R9, R10, R11: 1K0; R_Axial_DIN0204_L3.6mm_D1.6mm_P7.62mm_Horizontal
R12: 4K7; R_Axial_DIN0204_L3.6mm_D1.6mm_P7.62mm_Horizontal
R13, R14: 150K; R_Axial_DIN0204_L3.6mm_D1.6mm_P7.62mm_Horizontal
R18: 10K; R_Axial_DIN0204_L3.6mm_D1.6mm_P7.62mm_Horizontal
U1: AY-3-8912; DIP-28_W15.24mm_Socket
U4: AY-3-8910; DIP-40_W15.24mm_Socket
U16: 74LS138; DIP-16_W7.62mm_Socket
U18: 74LS00; DIP-14_W7.62mm_Socket

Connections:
+5V: R18.2, U1.3 (VCC), U1.17 (A8), U1.19 (BC2), U4.25 (A8), U4.28 (BC2), U4.40 (VCC), U16.16 (VCC), U18.14 (VCC); also elsewhere on the board
A1: U16.5 (E2); also elsewhere on the board
A14: U16.1 (A0); also elsewhere on the board
A15: U16.6 (E3); also elsewhere on the board
AUDIO: J4.4 (TipSW), J4.5 (RingSW); also elsewhere on the board
BC1: U1.20 (BC1), U4.29 (BC1), U18.3
BDIR: U1.18 (BDIR), U4.27 (BDIR), U18.6
CLKAY: U1.15 (CLOCK), U4.22 (CLK); also elsewhere on the board
D0: U1.28 (DA0), U4.37 (DA0); also elsewhere on the board
D1: U1.27 (DA1), U4.36 (DA1); also elsewhere on the board
D2: U1.26 (DA2), U4.35 (DA2); also elsewhere on the board
D3: U1.25 (DA3), U4.34 (DA3); also elsewhere on the board
D4: U1.24 (DA4), U4.33 (DA4); also elsewhere on the board
D5: U1.23 (DA5), U4.32 (DA5); also elsewhere on the board
D6: U1.22 (DA6), U4.31 (DA6); also elsewhere on the board
D7: U1.21 (DA7), U4.30 (DA7); also elsewhere on the board
EAR: R13.2; also elsewhere on the board
GND: J4.1 (Sleeve), R9.2, R11.2, U1.6 (GND), U4.1 (GND), U4.24 (~A9), U16.8 (GND), U18.7 (GND); also elsewhere on the board
IOA0: J20.1, U1.14 (IOA0), U4.21 (IOA0)
IOA1: J20.2, U1.13 (IOA1), U4.20 (IOA1)
IOA2: J20.3, U1.12 (IOA2), U4.19 (IOA2)
IOA3: J20.4, U1.11 (IOA3), U4.18 (IOA3)
IOA4: J20.5, U1.10 (IOA4), U4.17 (IOA4)
IOA5: J20.6, U1.9 (IOA5), U4.16 (IOA5)
IOA6: J20.7, U1.8 (IOA6), U4.15 (IOA6)
IOA7: J20.8, U1.7 (IOA7), U4.14 (IOA7)
IOB0: J19.1, U4.13 (IOB0)
IOB1: J19.2, U4.12 (IOB1)
IOB2: J19.3, U4.11 (IOB2)
IOB3: J19.4, U4.10 (IOB3)
IOB4: J19.5, U4.9 (IOB4)
IOB5: J19.6, U4.8 (IOB5)
IOB6: J19.7, U4.7 (IOB6)
IOB7: J19.8, U4.6 (IOB7)
IORQ: U16.4 (E1); also elsewhere on the board
MIC: R14.2; also elsewhere on the board
unnamed: C3.1, R6.1, R10.2, R11.1
unnamed: C4.1, R7.1, R8.2, R9.1
unnamed: C6.2, C7.2, R12.1, R13.1, R14.1
unnamed: C3.2, C7.1, J4.3 (Ring)
unnamed: C4.2, C6.1, J4.2 (Tip)
unnamed: R18.1, U18.9, U18.10, U18.12, U18.13
unnamed: R10.1, U1.5 (CH_A), U4.4 (AUD_A)
unnamed: R6.2, R7.2, U1.4 (CH_B), U4.3 (AUD_B)
unnamed: R8.1, U1.1 (CH_C), U4.38 (AUD_C)
unnamed: U16.12 (O3), U18.1
unnamed: U16.11 (O4), U18.5
unnamed: U16.10 (O5), U18.2, U18.4
RD: U16.3 (A2); also elsewhere on the board
RST: U1.16 (~RESET), U4.23 (~RESET); also elsewhere on the board
SPK: R12.2; also elsewhere on the board
WR: U16.2 (A1); also elsewhere on the board

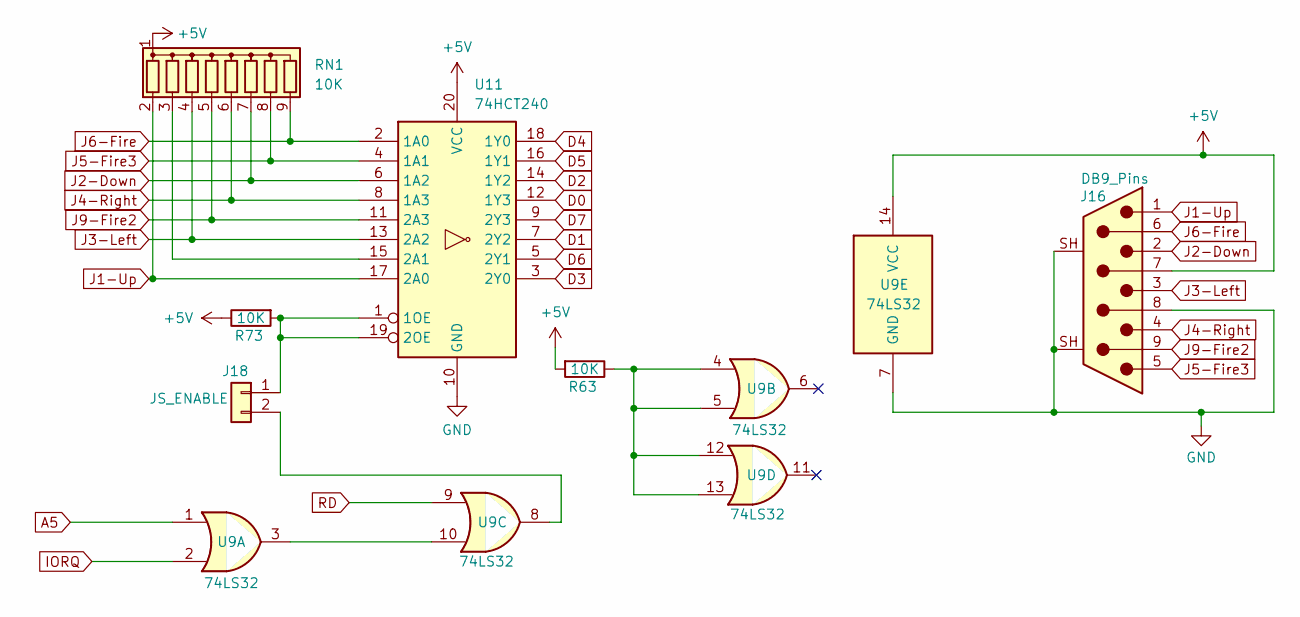
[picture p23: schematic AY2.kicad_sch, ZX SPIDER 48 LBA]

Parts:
J16: DB9_Pins; DSUB-9_Pins_Horizontal_P2.77x2.84mm_EdgePinOffset9.90mm_Hou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
J18: JS_ENABLE; PinHeader_1x02_P2.54mm_Vertical
R63, R73: 10K; R_Axial_DIN0204_L3.6mm_D1.6mm_P7.62mm_Horizontal
RN1: 10K; R_Array_SIP9
U9: 74LS32; DIP-14_W7.62mm_Socket
U11: 74HCT240; DIP-20_W7.62mm_Socket

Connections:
+5V: J16.7, R63.2, R73.1, RN1.1 (common), U9.14 (VCC), U11.20 (VCC); also elsewhere on the board
A5: U9.1; also elsewhere on the board
D0: U11.12 (1Y3); also elsewhere on the board
D1: U11.7 (2Y2); also elsewhere on the board
D2: U11.14 (1Y2); also elsewhere on the board
D3: U11.3 (2Y0); also elsewhere on the board
D4: U11.18 (1Y0); also elsewhere on the board
D5: U11.16 (1Y1); also elsewhere on the board
D6: U11.5 (2Y1); also elsewhere on the board
D7: U11.9 (2Y3); also elsewhere on the board
GND: J16.8, J16.SH (Shell), U9.7 (GND), U11.10 (GND); also elsewhere on the board
IORQ: U9.2; also elsewhere on the board
J1-Up: J16.1, RN1.2 (R1), U11.17 (2A0)
J2-Down: J16.2, RN1.7 (R6), U11.6 (1A2)
J3-Left: J16.3, RN1.4 (R3), U11.13 (2A2)
J4-Right: J16.4, RN1.6 (R5), U11.8 (1A3)
J5-Fire3: J16.5, RN1.8 (R7), U11.4 (1A1)
J6-Fire: J16.6, RN1.9 (R8), U11.2 (1A0)
J9-Fire2: J16.9, RN1.5 (R4), U11.11 (2A3)
unnamed: J18.1, R73.2, U11.1 (1OE), U11.19 (2OE)
unnamed: J18.2, U9.8
unnamed: R63.1, U9.4, U9.5, U9.12, U9.13
unnamed: RN1.3 (R2), U11.15 (2A1)
unnamed: U9.3, U9.10
RD: U9.9; also elsewhere on the board

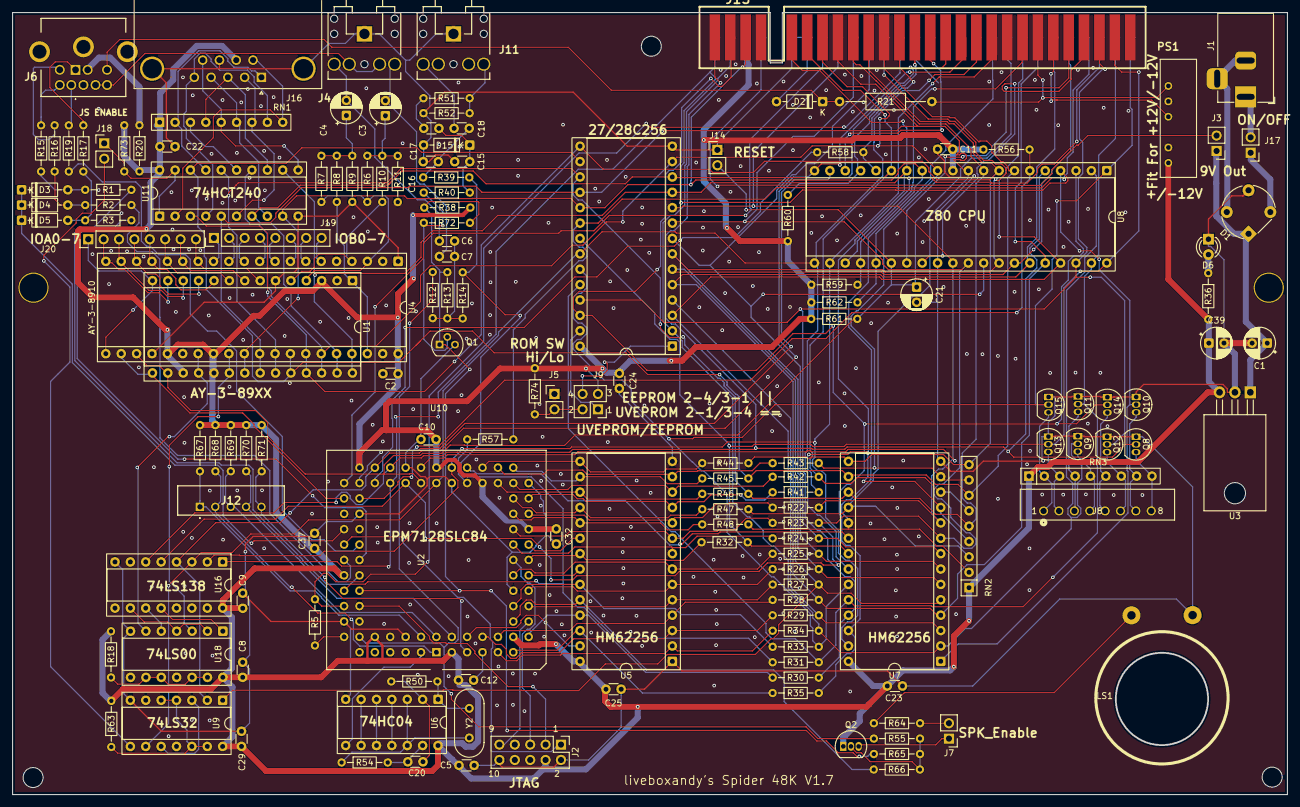
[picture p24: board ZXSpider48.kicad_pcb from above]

Board: 2 copper layers, 210.5 x 129.1 mm, 155 parts (0 on the bottom side), 179 nets.

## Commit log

2026-06-21 Initial Release of Files
    [1658998-1.stp, 5-520315-5.stp, 9Pin MiniDIN KMDGX-9S-BS-1.stp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]
2026-06-24 Add files via upload
    Added optional +/-12V for IF2 Serial support. Only fit if required.
    Added jumper J18 to enable/disable Joystick interface ( fitted to enable, remove to disable).
    [AY2.kicad_sch, CLS0402MA-1.stp, CMS-40558N-L152B.stp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]
2026-06-25 Added header for AY3-8910 IOB (J18) and moved position of U1 and U4
    * Routed AY3-8910 IOB Bits0-7 to header J18 Pins 1(Bit0)- 8(Bit7)
    * AY3-8910 IOA Bits 0-7 can be picked from U1 pins 7(Bit7)-14(Bit0)
    * AY3-8912 IOA Bits 1-7 can be picked from U4 Pins 14(Bit7)-20(Bit1)
    * AY3-8912 IOA Bit0 can be picked from J20
    [AY2.kicad_sch, Kempston.kicad_sch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]
2026-06-26 Add files via upload
    Changed ROM select to 2 pin rather than 3 pin header
    [Kempston.kicad_sch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]
2026-07-12 Add files via upload
    Corrected R58 value 470R
    Added jumper for EPROM/EEPROM select
    Added jumper notations
    Added more buffers to clock signal
    [AY2.kicad_sch, Kempston.kicad_sch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]
2026-08-02 Add files via upload
    Minor moves to J6/R15/16/17/18/73/J18 along with rotation and move of Q2
    [AY2.kicad_sch, Kempston.kicad_sch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]
2026-08-22 Add files via upload
    Minor cosmetic changes to silkscreen and README.MD
    No changes to schematic or PCB layout.
    [AY2.kicad_sch, Kempston.kicad_sch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]
2026-09-06 Add files via upload
    Minor change to reduce PCB size to better fit some Rubber cases.
    [ZXSpider48.kicad_pcb]
2026-09-20 Add files via upload
    Updated to V1,7 Added resistor for auto RGB switching. Added resistor/zener for auto AV switching. Updated README.MD
    [AY2.kicad_sch, Kempston.kicad_sch, SM230332-2.stp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]
